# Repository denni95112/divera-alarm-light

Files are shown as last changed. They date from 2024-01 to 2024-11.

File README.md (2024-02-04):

# Divera Alarm Light 

Das Divera Alarm Light lässt einen LED Ring im Alarmfall rot und blau leuchten. 

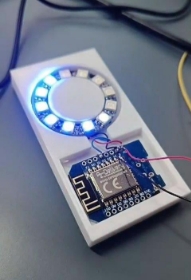
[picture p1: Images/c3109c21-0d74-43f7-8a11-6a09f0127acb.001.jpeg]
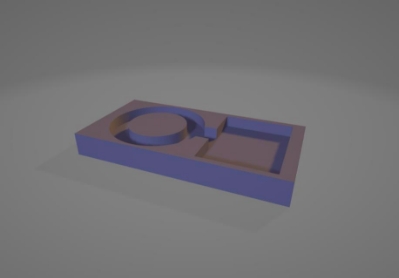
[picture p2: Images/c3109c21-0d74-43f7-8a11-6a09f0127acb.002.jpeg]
 


## Teile 

D1 Mini NodeMcu ESP8266-12F [https://amzn.to/47EQ84x ](https://amzn.to/47EQ84x)

38mm WS2812B RGB LED Ring [https://amzn.to/47FUhp2 ](https://amzn.to/47FUhp2)

USB C Buchse <https://amzn.to/48FoeH0>

## Flashen 

Laden Sie den „CH341SER“ Treiber herunter und installieren Sie diesen. Eine Anleitung finden Sie hier[ https://www.makershop.de/ch340-341-usb-installieren/  ](https://www.makershop.de/ch340-341-usb-installieren/)

Laden Sie ESPHome-Flasher herunter und führen Sie das Programm aus, eine Anleitung finden Sie hier[ https://edistechlab.com/hc-sr501-pir-motion-sensor/?v=3a52f3c22ed6 ](https://edistechlab.com/hc-sr501-pir-motion-sensor/?v=3a52f3c22ed6)

Wählen Sie den Serial Port des ESP die Sie über USB an Ihren PC anschließen. Wählen Sie die Firmware „DiveraAlarmLight.ino.d1\_mini.bin“ dieser ZIP beigefügt ist. Klicken Sie auf Flash und warten Sie bis der Vorgang abgeschlossen ist.



Für Menschen mit Programmierkenntnissen ist die INO Datei des Arduino Projektes beigefügt um Anpassungen vorzunehmen, falls gewünscht.

## Zusammenbau 

3D drucken Sie das Gehäuse und legen sich die Bauteile inkl. etwas Leitung bereit. 

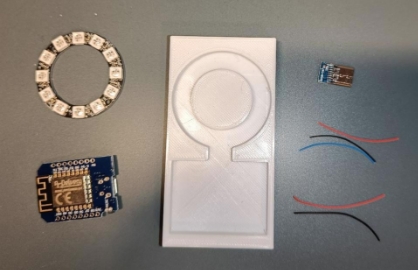
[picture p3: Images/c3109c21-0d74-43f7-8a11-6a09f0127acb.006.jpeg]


Löten Sie Leitungen für Vcc, GND und Data an die Input Pins des LED Rings. 

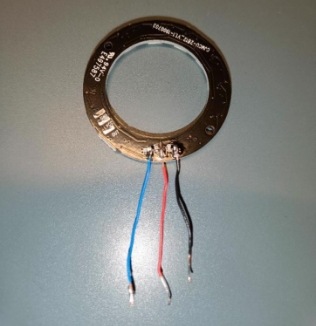
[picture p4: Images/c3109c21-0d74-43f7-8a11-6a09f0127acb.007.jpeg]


Löten Sie die anderen Enden der Leitungen an den ESP, die Data Leitung (hier blau) wird an D2 gelötet. 

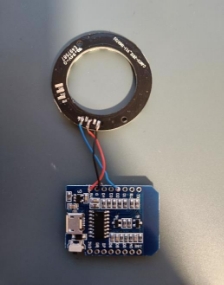
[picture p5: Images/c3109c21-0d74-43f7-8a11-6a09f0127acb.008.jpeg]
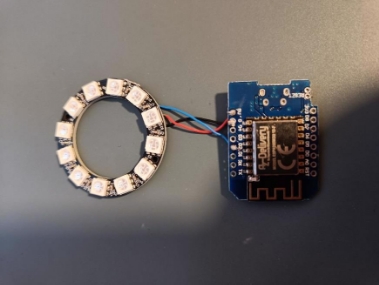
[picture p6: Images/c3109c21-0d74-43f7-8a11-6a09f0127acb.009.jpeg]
 

Kleben Sie den LED Ring mit etwas Heißkleber im Gehäuse fest. Kleben Sie außerdem die USB C Buchse an die Rechte Seite des Gehäuses. Sie können des ESP ebenfalls festkleben, wenn Sie sich sicher sind, dass alles funktioniert. Ich empfehle diesen erst einmal mit etwas Klebeband zu fixieren und auf den ersten (Probe)Alarm zu warten, bevor der ESP mit Heißkleber fixiert wird.

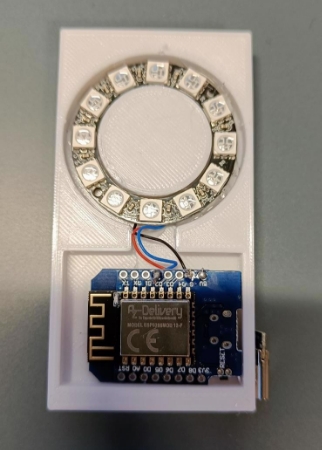
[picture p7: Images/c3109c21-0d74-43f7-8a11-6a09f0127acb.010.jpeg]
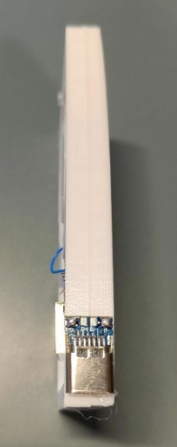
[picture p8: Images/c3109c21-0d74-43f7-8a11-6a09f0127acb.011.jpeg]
  

Löten Sie Leitungen für VCC und GND an die USB C Buche und verbinden Sie diese mit den VCC und GND Pins des ESP. 

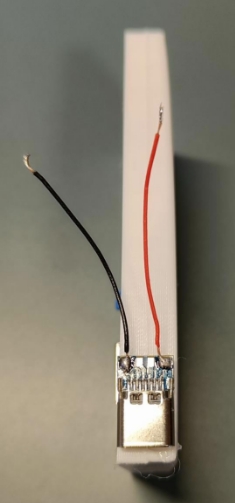
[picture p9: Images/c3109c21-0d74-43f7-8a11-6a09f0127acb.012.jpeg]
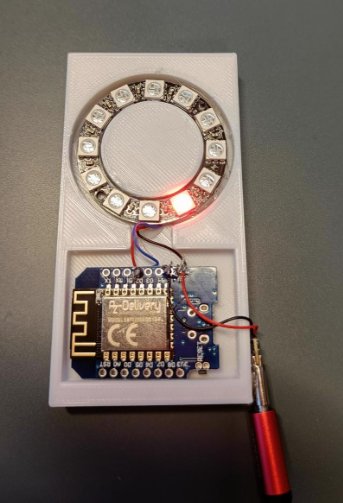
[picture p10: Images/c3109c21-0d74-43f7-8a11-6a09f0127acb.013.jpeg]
 

Ihr „Divera Alarm Light“ kann nun über USB C mit Strom versorgt werden. 

## Einrichtung 



Öffnen Sie die WLAN Einstellungen Ihres Smartphones und verbinden Sie sich mit dem Netzwerk „Divera Alarm Light“. Sie sollten im Anschluss eine Benachrichtigung erhalten, um sich im Netzwerk anzumelden. 



Tippen Sie auf „Configure WiFi“, sollten sich im Feld „API Key“ undefinierbare Zeichen befinden, löschen Sie diese. 



Tippen Sie auf Ihr WLAN-Netzwerk, dieses erscheint dann im Feld „SSID“. Geben Sie ihr WLAN Passwort im Feld „Password“ ein. 

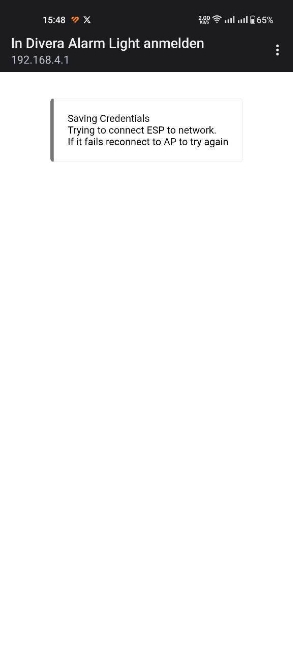
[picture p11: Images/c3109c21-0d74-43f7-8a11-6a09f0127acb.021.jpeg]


Fügen Sie Ihren Divera API Key in das Feld „API Key“ ein und tippen Sie auf „Save“. 

Sollte Ihr API Key oder WLAN Passwort fehlerhaft sein, leuchtet eine LED des Rings rot auf. Warten Sie in diesem Fall 10 Sekunden und beginnen Sie mit der Einrichtung von vorn.

Sollte keine LED leuchten und Ihr Smartphone hat sich wieder mit Ihrem Netzwerk verbunden, war die Einrichtung erfolgreich. Wenn Sie Ihr Gerät neu starten, wird eine LED des Rings kurz grün aufleuchten, sobald sich Ihr Gerät mit Ihrem WLAN Netzwerk verbunden hat.

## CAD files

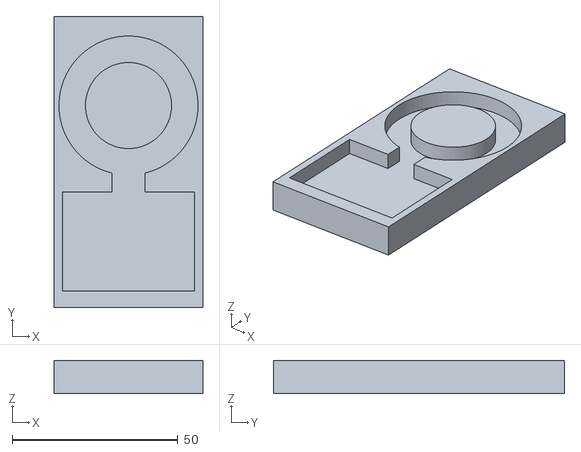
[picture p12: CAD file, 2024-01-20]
3D Model/Case.stl
45.0 x 88.0 x 10.0

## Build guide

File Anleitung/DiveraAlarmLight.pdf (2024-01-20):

# Divera Alarm Light

Das Divera Alarm Light lässt einen LED Ring im Alarmfall rot und blau leuchten.

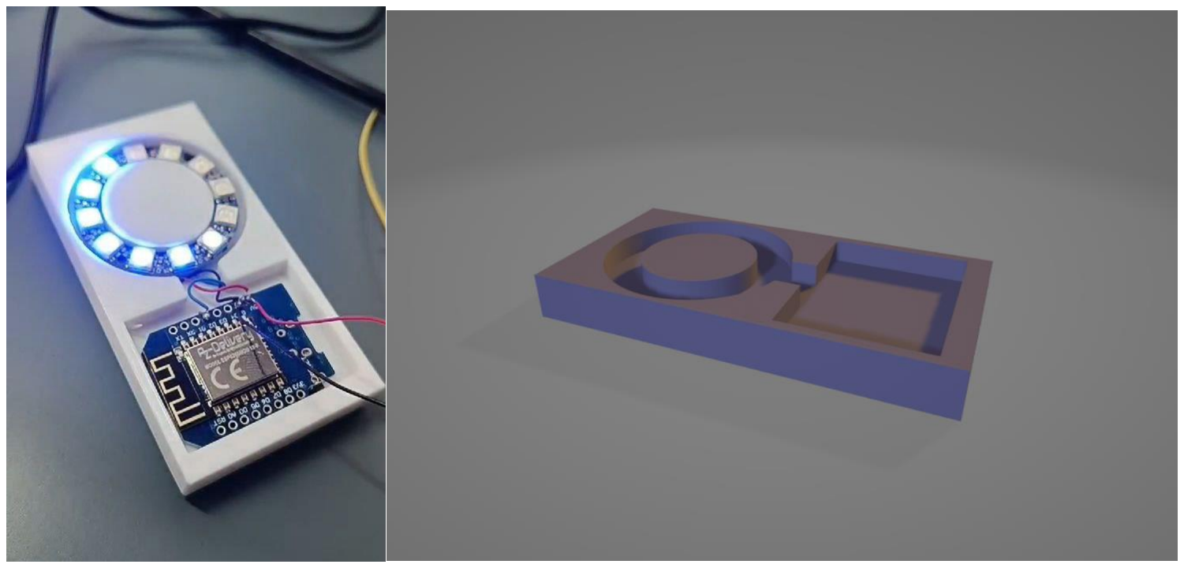
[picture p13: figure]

## Teile

D1 Mini NodeMcu ESP8266-12F https://amzn.to/47EQ84x

38mm WS2812B RGB LED Ring
https://amzn.to/47FUhp2

USB C Buchse
https://amzn.to/48FoeH0

## Flashen

Laden Sie den „CH341SER“ Treiber herunter und installieren Sie diesen. Eine Anleitung finden Sie hier https://www.makershop.de/ch340-341-usb-installieren/
Laden Sie ESPHome-Flasher herunter und führen Sie das Programm aus, eine Anleitung finden Sie hier https://edistechlab.com/hc-sr501-pir-motion-sensor/?v=3a52f3c22ed6
Wählen Sie den Serial Port des ESP die Sie über USB an Ihren PC anschließen.
Wählen Sie die Firmware „DiveraAlarmLight.ino.d1_mini.bin“ dieser ZIP beigefügt ist.
Klicken Sie auf Flash und warten Sie bis der Vorgang abgeschlossen ist.

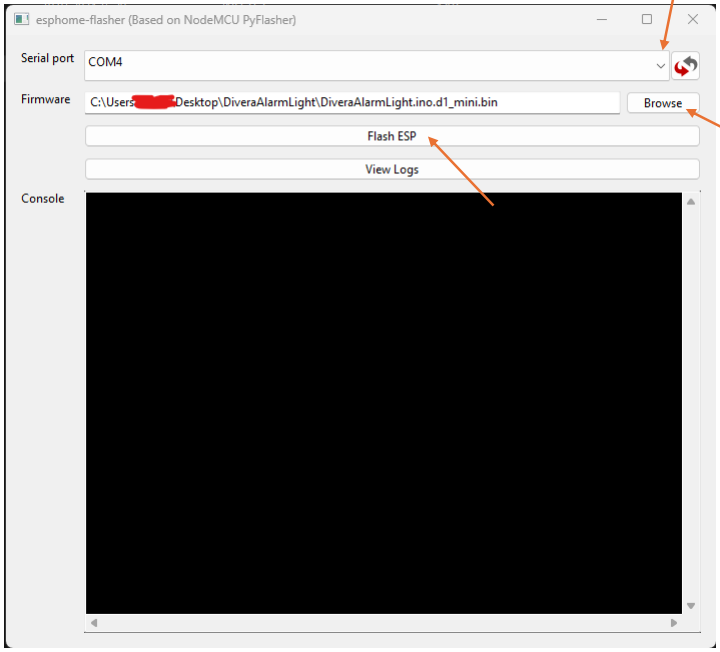
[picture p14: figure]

Für Menschen mit Programmierkenntnissen ist die INO Datei des Arduino Projektes beigefügt um Anpassungen vorzunehmen, falls gewünscht.

## Zusammenbau

3D drucken Sie das Gehäuse und legen sich die Bauteile inkl. etwas Leitung bereit.

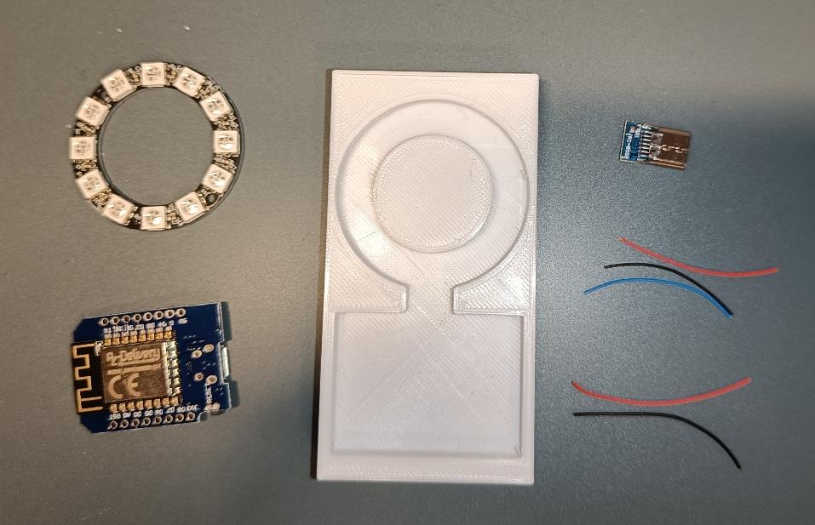
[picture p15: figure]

Löten Sie Leitungen für Vcc, GND und Data an die Input Pins des LED Rings.

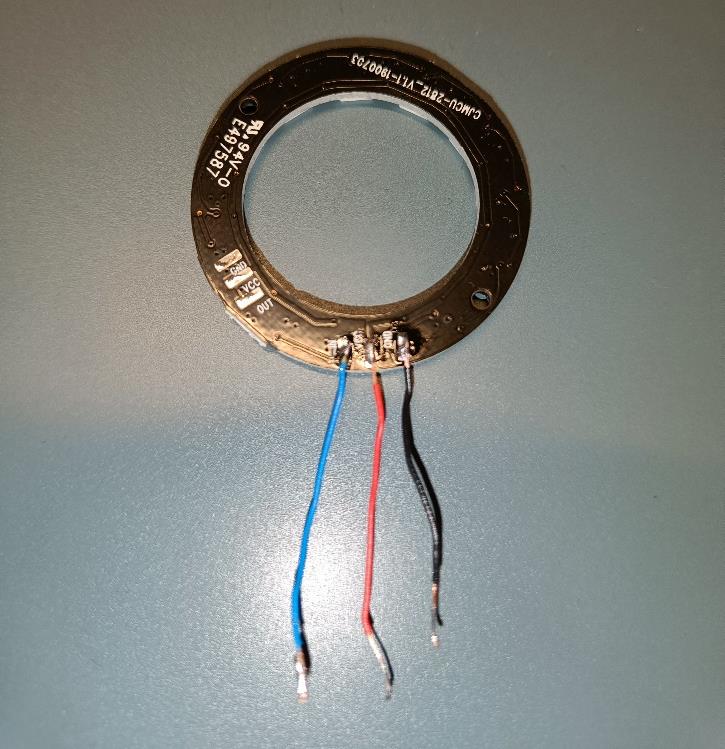
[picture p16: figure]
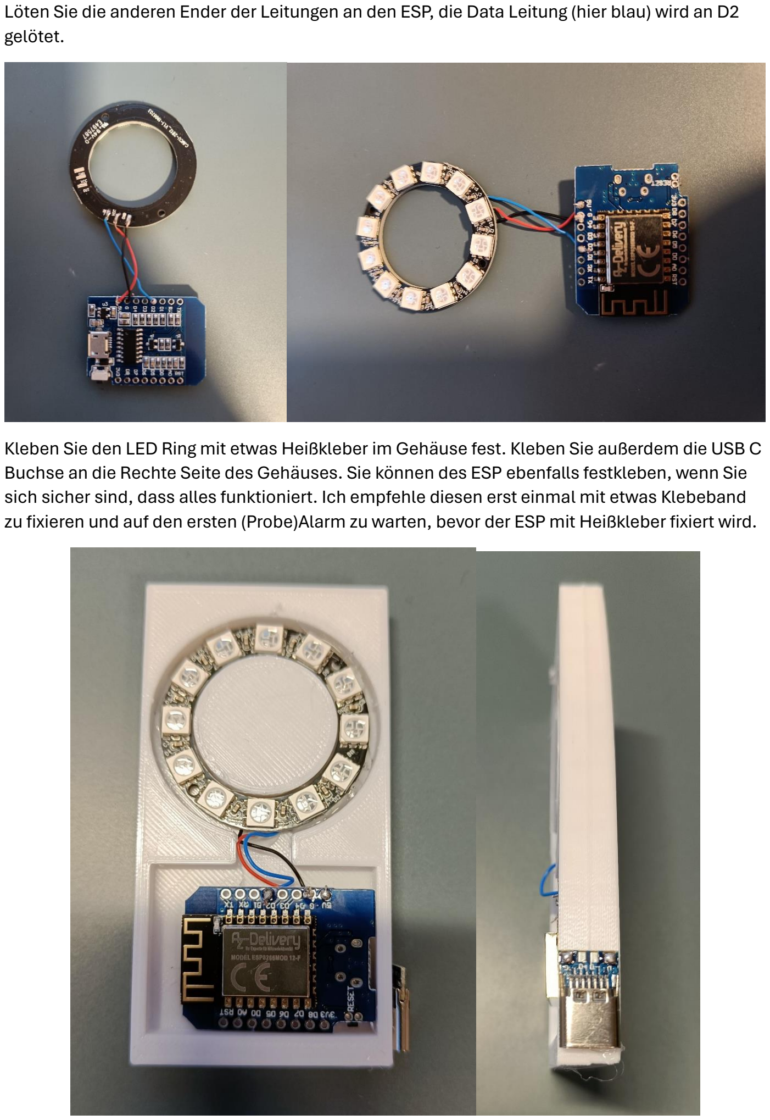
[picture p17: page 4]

Löten Sie die anderen Ender der Leitungen an den ESP, die Data Leitung (hier blau) wird an D2 gelötet.

Kleben Sie den LED Ring mit etwas Heißkleber im Gehäuse fest. Kleben Sie außerdem die USB C Buchse an die Rechte Seite des Gehäuses. Sie können des ESP ebenfalls festkleben, wenn Sie sich sicher sind, dass alles funktioniert. Ich empfehle diesen erst einmal mit etwas Klebeband zu fixieren und auf den ersten (Probe)Alarm zu warten, bevor der ESP mit Heißkleber fixiert wird.

Löten Sie Leitungen für VCC und GND an die USB C Buche und verbinden Sie diese mit den VCC und GND Pins des ESP.

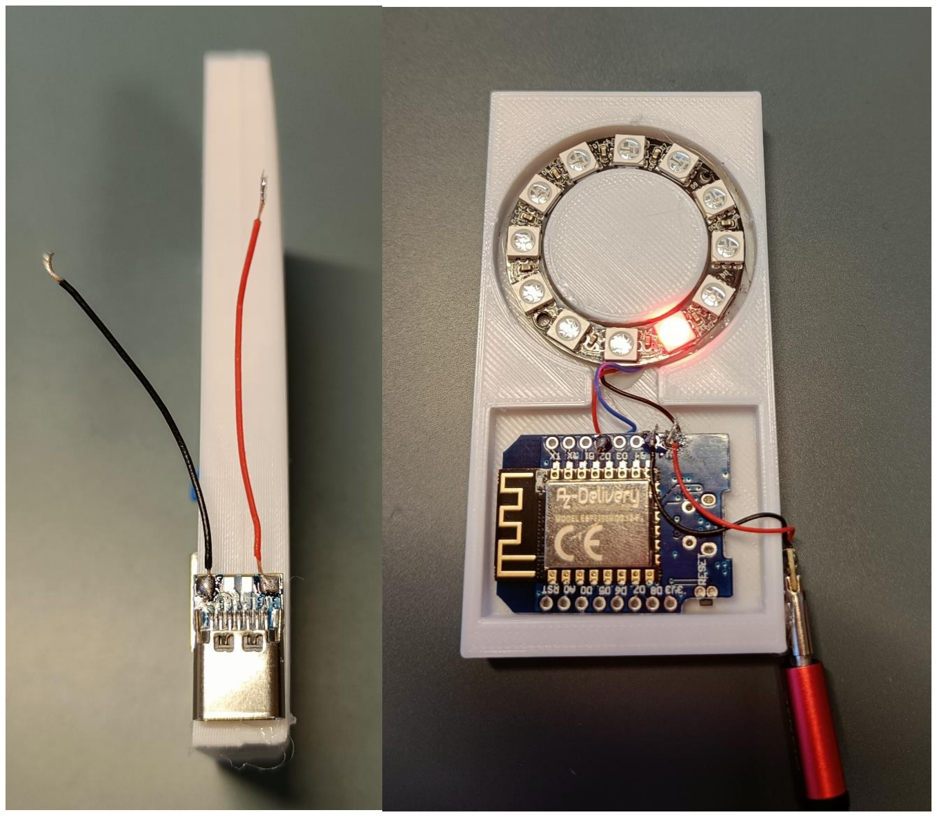
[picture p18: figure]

Ihr „Divera Alarm Light“ kann nun über USB C mit Strom versorgt werden.

# Einrichtung

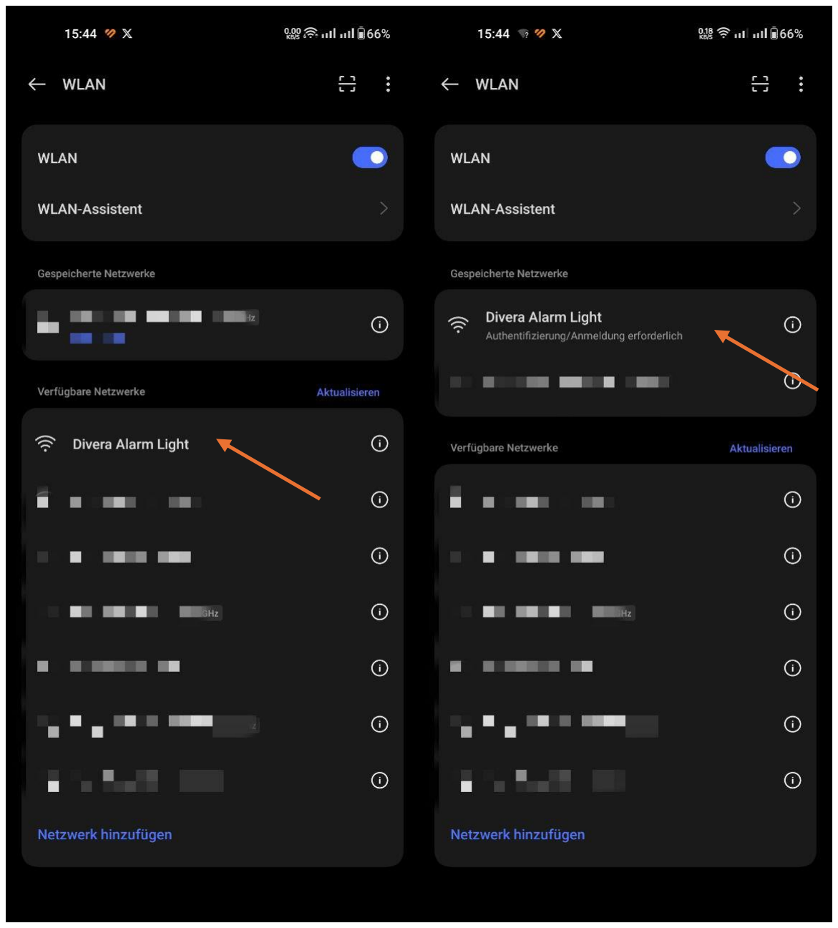
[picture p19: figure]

Öffnen Sie die WLAN Einstellungen Ihres Smartphones und verbinden Sie sich mit dem Netzwerk „Divera Alarm Light“. Sie sollten im Anschluss eine Benachrichtigung erhalten, um sich im Netzwerk anzumelden.

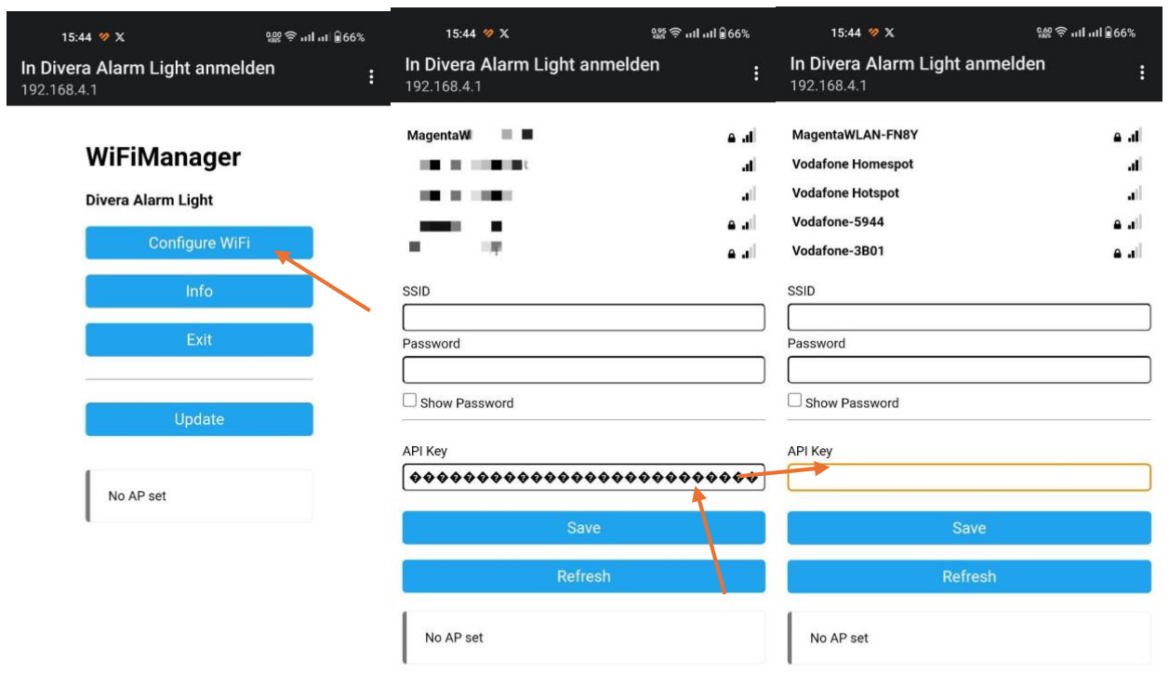
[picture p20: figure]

Tippen Sie auf „Configure WiFi“, sollten sich im Feld „API Key“ undefinierbare Zeichen befinden, löschen Sie diese.

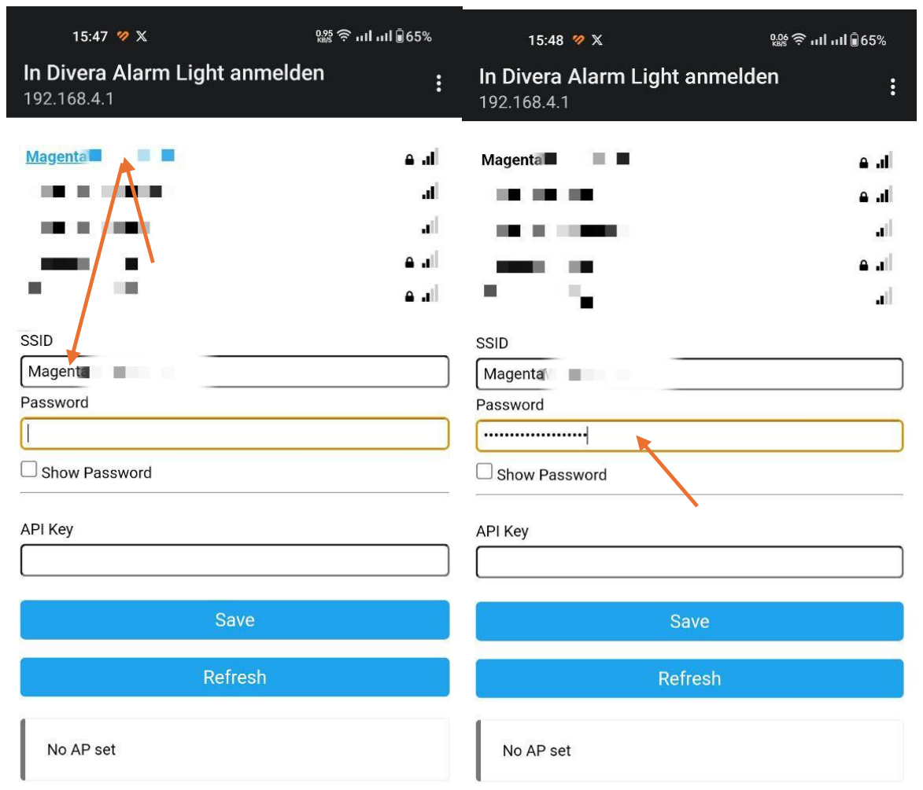
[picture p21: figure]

Tippen Sie auf Ihr WLAN-Netzwerk, dieses erscheint dann im Feld „SSID“. Geben Sie ihr WLAN Passwort im Feld „Password“ ein.

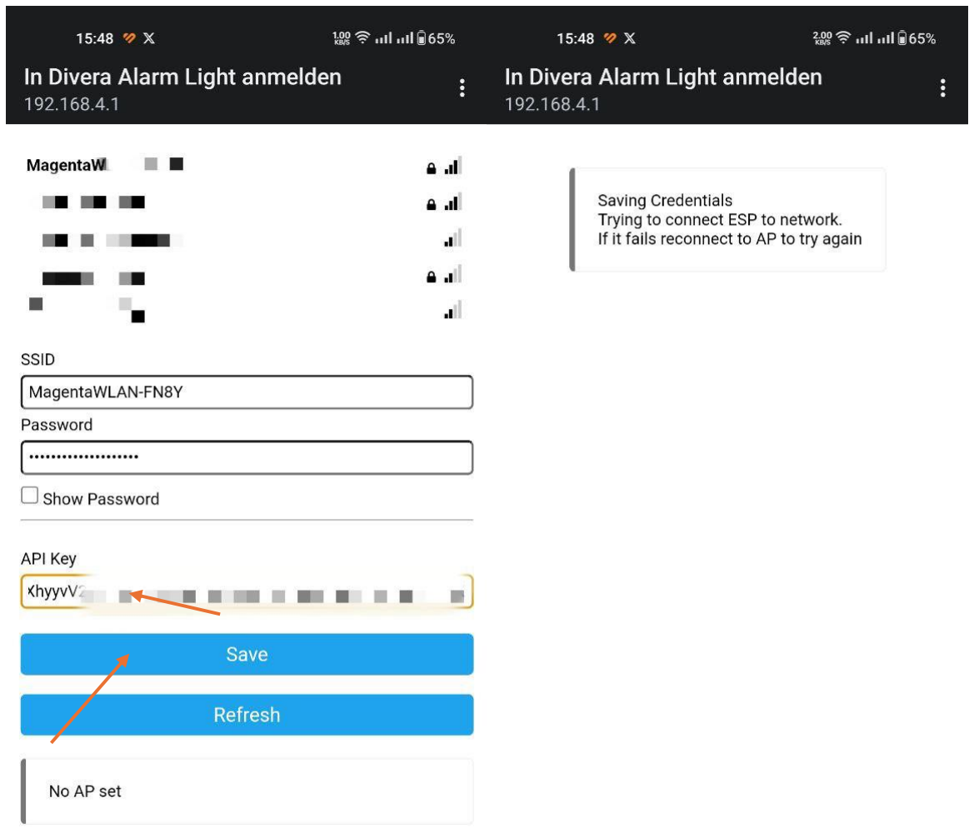
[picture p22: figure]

Fügen Sie Ihren Divera API Key in das Feld „API Key“ ein und tippen Sie auf „Save“.
Sollte Ihr API Key oder WLAN Passwort fehlerhaft sein, leuchtet eine LED des Rings rot auf. Warten Sie in diesem Fall 10 Sekunden und beginnen Sie mit der Einrichtung von vorn. Sollte keine LED leuchten und Ihr Smartphone hat sich wieder mit Ihrem Netzwerk verbunden, war die Einrichtung erfolgreich. Wenn Sie Ihr Gerät neu starten, wird eine LED des Rings kurz grün aufleuchten, sobald sich Ihr Gerät mit Ihrem WLAN Netzwerk verbunden hat.

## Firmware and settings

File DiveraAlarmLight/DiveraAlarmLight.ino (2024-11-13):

#include <ESP8266WiFi.h>
#include <WiFiClient.h>
#include <FastLED.h>
#include <WiFiUdp.h>
#include <ESP8266HTTPClient.h>
#include <ESP8266WebServer.h>
#include <WiFiManager.h>  
#include <EEPROM.h>

const int eepromAddress = 0; // EEPROM address to store the API key
char apiKey[65];
int errorCounter = 0;
#define DATA_PIN 4

// Define the array of leds
const int NUM_LEDS = 12;
CRGB leds[NUM_LEDS];

String apiPath = "https://app.divera247.com/api/v2/alarms?accesskey="; 
String apiKeyString = "";

WiFiManager wm;
   
void setup()
{
  Serial.begin(115200);
  FastLED.addLeds<WS2812B, DATA_PIN, GRB>(leds, NUM_LEDS);  //m GRB ordering is typical
  FastLED.setBrightness(255);
  allOff();
  
  EEPROM.begin(65); // Adjust the size based on your needs
  EEPROM.get(eepromAddress, apiKey);

  WiFiManagerParameter customApiKey("api_key", "API Key", apiKey, 64);
  wm.addParameter(&customApiKey);

  leds[0] = CRGB::Red;
  show();
  
  if(!wm.autoConnect("Divera Alarm Light")){
    Serial.println("Failed to connect and hit timeout");
    leds[0] = CRGB::Red;
    show();
    delay(3000);
    ESP.reset();
    delay(5000);
  }
  allOff();
  Serial.println("CONNECTED");
  leds[0] = CRGB::Green;
  show();
  delay(1000);
  allOff();
  Serial.println("Stetup done");

  strncpy(apiKey, customApiKey.getValue(), sizeof(apiKey) - 1);
  apiKey[sizeof(apiKey) - 1] = '\0'; // Ensure null-termination
  EEPROM.put(eepromAddress, apiKey);
  EEPROM.commit();

  apiKeyString = String(apiKey);
}

void loop() {
  if(doRequest()){
    alarm();
    //15 min delay
    delay(300000 * 3); 
  }else{
    
  }
  delay(10000);
}

void alarm(){
  for(short i = 0; i < 90; i++){
    spinColor(CRGB::Blue, 6, 1);
    spinColor(CRGB::Red, 6, 1);
  }
  allOff();
}

void allOff(){
  FastLED.clear();  // clear all pixel data
  show();
}

void show(){
  FastLED.show();
  FastLED.delay(5);
}

bool doRequest(){
  std::unique_ptr<BearSSL::WiFiClientSecure>client(new BearSSL::WiFiClientSecure);
  bool alarm = false;
  HTTPClient http;
  client->setInsecure();
  Serial.println((apiPath + apiKeyString).c_str());
  http.begin(*client, (apiPath + apiKeyString).c_str());
  int httpResponseCode = http.GET();
  Serial.print("HTTP Response code: ");
  Serial.println(httpResponseCode);   
  if (httpResponseCode == HTTP_CODE_OK) {
    errorCounter = 0;
    String payload = http.getString();
    if(payload.length() >= 64 && payload.indexOf("\"closed\":false") > 0)
      alarm = true;
  }
  else {
    Serial.println("Error");
    errorCounter = errorCounter + 1;
    if(errorCounter >= 30){
      errorCounter = 0;
      leds[0] = CRGB::Red;
      show();
      Serial.println("Resetting WiFi settings...");
      wm.resetSettings();
      delay(5000);
      ESP.reset();
      delay(5000);
    }
    delay(60 * 1000);
  }
  http.end();
  return alarm;
}

void spinColor(CRGB color, short numOfLedsToSpin, int spinForSeconds){
  int offset = 0;
  for(int i=0 ; i<spinForSeconds*20; i++){
    for(int a=0; a<offset; a++){
        if(a > NUM_LEDS){
          leds[a - NUM_LEDS] = CRGB::Black;
        }else{
          leds[a] = CRGB::Black;
        }
      }
    for(int b=offset; b<offset+numOfLedsToSpin; b++){
      if(b > NUM_LEDS){
        leds[b - NUM_LEDS] = color;
      }else{
        leds[b] = color;
      }
    }
    for(int c=offset+numOfLedsToSpin; c<NUM_LEDS; c++){
      if(c > NUM_LEDS){
        leds[c - NUM_LEDS] = CRGB::Black;
      }else{
        leds[c] = CRGB::Black;
      }
    }
    show();
    delay(50);
    offset++;
    if(offset >= 11){
      offset = 0;
    }
  }

}
